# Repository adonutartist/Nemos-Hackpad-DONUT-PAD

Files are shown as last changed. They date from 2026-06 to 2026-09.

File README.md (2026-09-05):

<div align="center">

# Donut Pad :O

*A 12-key macropad with a rotary encoder and OLED display, built for Hack Club's Stardance YSWS.*

Copy of White Creative Project Cover Page

</div>

---

DEMO VIDEO: https://youtube.com/shorts/37Y9ueW4ZXs?feature=share

---

## About

Donut Pad is a 12 key macropad with a rotary encoder and an OLED display, built to function as a gamepad/game controller. It runs using a custom KiCad-designed PCB, and sits inside a integrated plate mounted case topped with a Kintsugi inspired plate with gold/silver cut accents.

## Features

- 12 Mechanical Keys:
  - 4 keys for D-Pad (Up, Down, Left, Right)
  - 4 keys for Action buttons (J, K, U, I)
  - Start and Esc buttons
  - Left and Right shoulder buttons
- EC11 Rotary Encoder for volume (rotation only press is not wired/functional)
- 128x32 OLED display (not functional)
- Seeed XIAO RP2040
- Clean custom PCB
- Sandwich mounting style case

---

## Exploded View

Everything fits together using 4 M3 screws and heatset inserts, integrated plate mount style, with 2 separate printed pieces:

- **Case Shell** where the PCB sits. Designed to be transparent so the PCB remains visible; clear resin printing (or transparent FDA) recommended for the best result. (I did it all black cuz resin is costly)
- **Case Top Plate** holds all keyholes, the OLED cutout, and the rotary encoder cutout. Features a black body with gold cut accents inspired by Kintsugi, the Japanese art of repairing broken pottery with gold.

Assembled view of Donut Pad:

cad model assembled view

Exploded view of Donut Pad:

cad model exploded view

Made in Fusion 360.

---

## BOM (Bill of Materials)

| Component | Qty | Purpose |
|---|-----|---|
| Seeed XIAO RP2040 | 1 | Main controller |
| MX-Style switches | 12 | Key matrix |
| DSA keycaps | 12 | Keycaps |
| EC11 Rotary encoder | 1 | Scroll/volume input |
| 0.91" 128x32 OLED display | 1 | Status display |
| 1N4148 Diodes (THT) | 12 | Matrix ghosting protection |
| M3x16mm screws | 4 | Case assembly |
| M3x5x4mm heatset inserts | 4 | Case assembly |
| Custom PCB | 1 | — |
| 3D printed transparent case shell | 1 | Clear resin / transparent FDA |
| 3D printed Kintsugi-inspired case plate | 1 | Top plate with gold accents |

---

## Circuit Diagram

Designed in KiCad. The silkscreen art includes a custom dooOOnut mascot and the Hack Club logo.

PCB Schematic:

schematic kicad

PCB Board:

PCB kicad

---

## Known Issues

- **OLED display is not functional.** The PCB footprint was laid out assuming the module's pin header runs top-to-bottom (GND, 3V3, SCL, SDA), but the physical module's actual pin order runs bottom-to-top — so the connections ended up reversed on the board. Attempted a rework with a desoldering pump and solder wick to lift the header and rewire it with jumpers, but the pads wouldn't fully clear, so the fix was abandoned for now. Keys and the rotary encoder work fully; the OLED does not currently display anything.
- RGB underglow LEDs were dropped from the design due to DRC errors during PCB routing.

---

## Firmware

Built in the Arduino IDE using:

- Keyboard (built into the Raspberry Pi Pico/RP2040 board core)
- Adafruit GFX
- Adafruit SSD1306

Flash **`Macropad.ino`** to the board. The firmware:

- Scans the 4x3 matrix with debouncing and sends the mapped key on each press.
- Decodes the rotary encoder via interrupt-driven quadrature detection, sending Up/Down arrow keys.
- Drives the OLED status display — currently has no visible effect due to the wiring issue above, but the code is left in place for whenever the display gets rewired.

---

## OLED animation:

- Animated GIF on the OLED.

WIP preview of the OLED animation:



I might add more stuff in the future! That's it for now.

---

## Gallery

<table>
<tr>
<td width="50%">

</td>
<td width="50%">

</td>
</tr>

<tr>
<td width="50%">

</td>
<td width="50%">

</td>
</tr>

<tr>
<td width="50%">
Snapchat-1131476981
</td>
<td width="50%">
Snapchat-2125285501
</td>
</tr>
</table>

---

<div align="center">
nemo
</div>

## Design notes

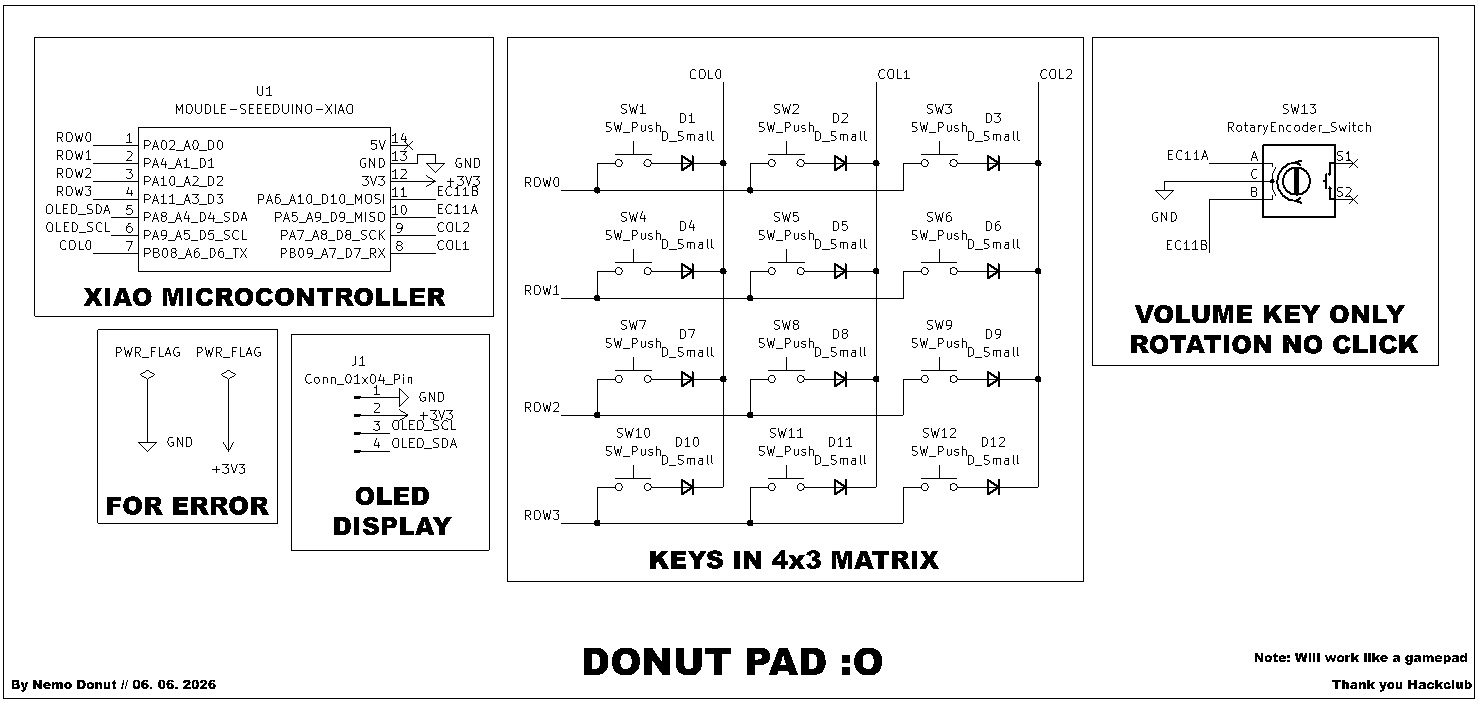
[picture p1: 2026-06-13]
assets/schematic kicad.jpg

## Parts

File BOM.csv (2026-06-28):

1x Seeed XIAO RP2040
12x MX-Style switches
12x DSA keycaps
1x EC11 Rotary encoder
1x 0.91 inch 128x32 OLED display
12x through-hole 1N4148 Diodes
4x M3x16mm screws
4x M3x5mx4mm heatset inserts
PCB (100mmx100mm)
1x 3D printed Transparent case shell (Clear Transparent Resin/Transparent FDA)
1x 3D printed Kintsugi inspired case plate

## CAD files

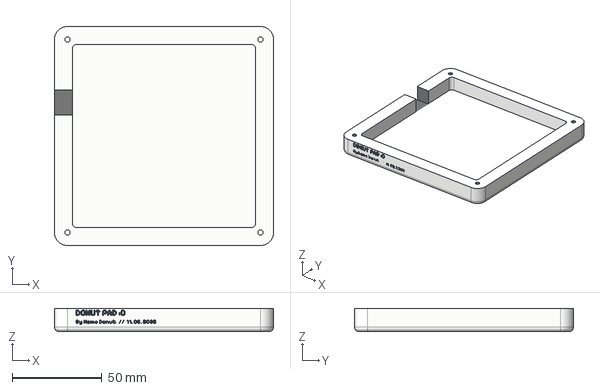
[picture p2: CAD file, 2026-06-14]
Production/Main Body Shell.step
122.0 x 122.0 x 13.0 mm

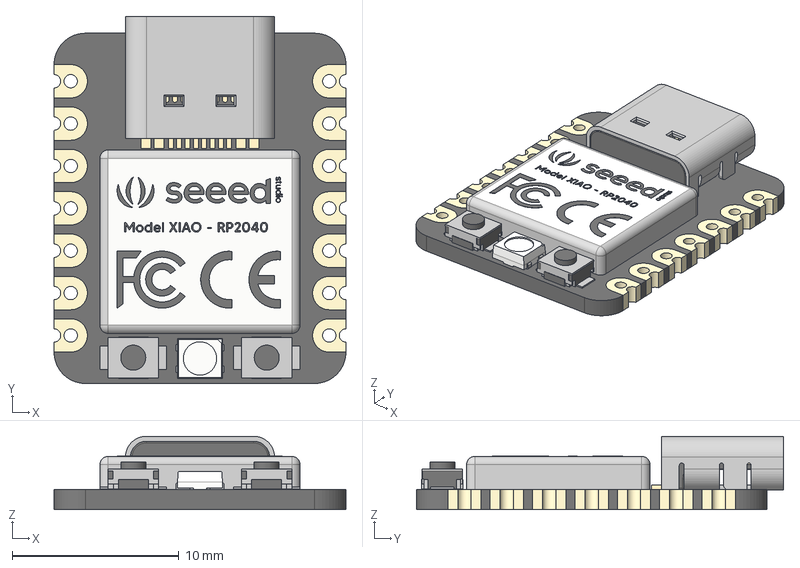
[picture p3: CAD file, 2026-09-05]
assets/Seeed Studio XIAO RP2040 v26.step
17.5 x 22.0 x 4.40 mm
type-c v2
smd_button v3
DOUT
DIN
VSS
VDD
smd_button v3(Mirror)

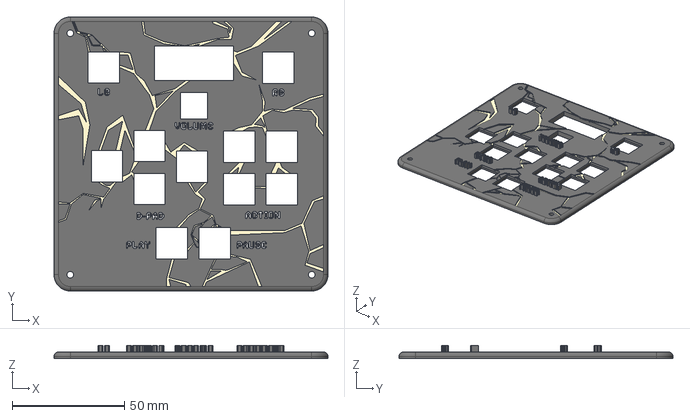
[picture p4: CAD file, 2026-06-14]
Production/Top Plate.step
122.0 x 122.0 x 6.00 mm

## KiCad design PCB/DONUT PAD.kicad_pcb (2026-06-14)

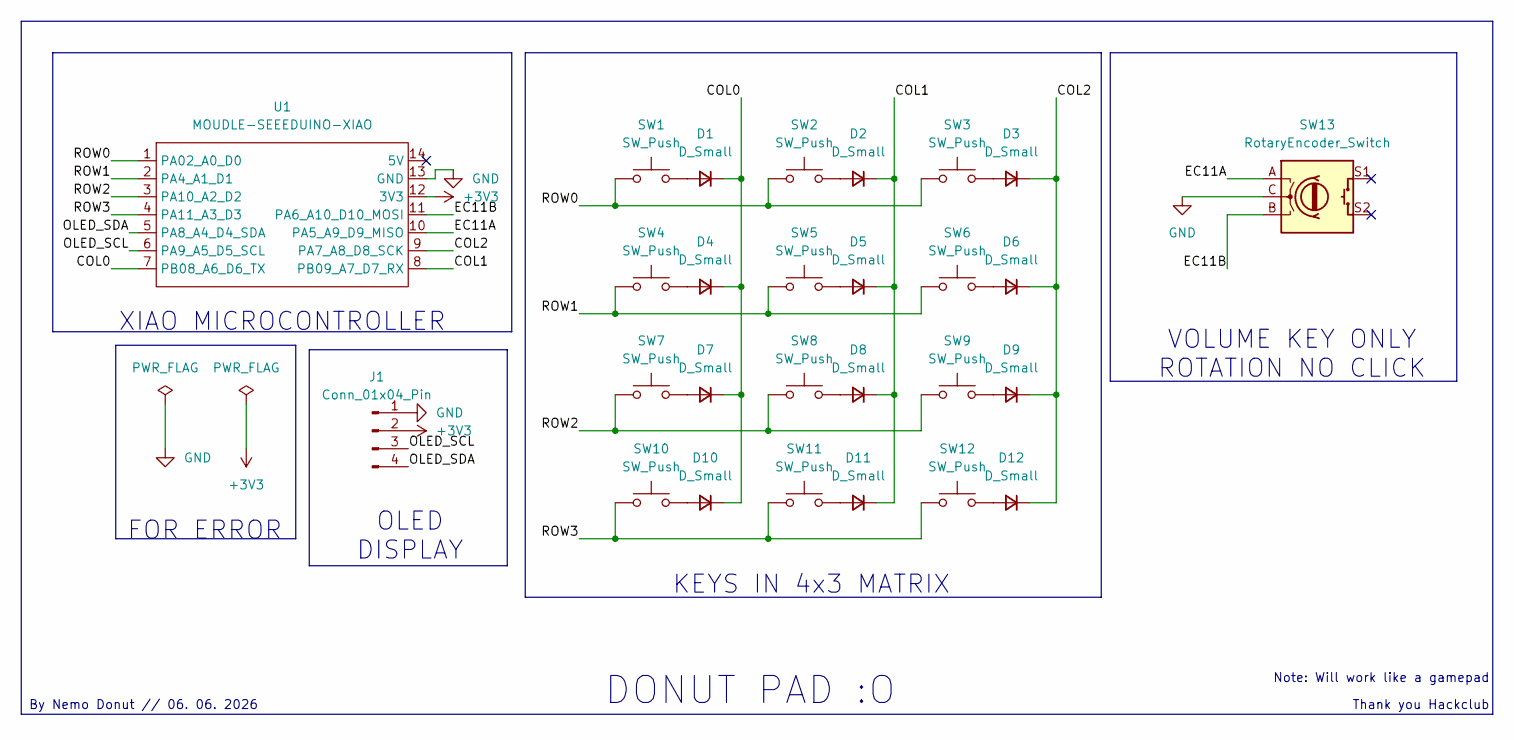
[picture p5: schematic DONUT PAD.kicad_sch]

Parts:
D1, D2, D3, D4, D5, D6, D7, D8, D9, D10, D11, D12: D_Small; D_DO-35_SOD27_P7.62mm_Horizontal
J1: Conn_01x04_Pin; PinHeader_1x04_P2.54mm_Vertical
SW1, SW2, SW3, SW4, SW5, SW6, SW7, SW8, SW9, SW10, SW11, SW12: SW_Push; SW_Cherry_MX_1.00u_PCB
SW13: RotaryEncoder_Switch; RotaryEncoder_Alps_EC11E-Switch_Vertical_H20mm
U1: MOUDLE-SEEEDUINO-XIAO; XIAO-Generic-Hybrid-14P-2.54-21X17.8MM

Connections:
+3V3: J1.2, U1.12 (3V3)
/COL0: D1.1 (K), D4.1 (K), D7.1 (K), D10.1 (K), U1.7 (PB08_A6_D6_TX)
/COL1: D2.1 (K), D5.1 (K), D8.1 (K), D11.1 (K), U1.8 (PB09_A7_D7_RX)
/COL2: D3.1 (K), D6.1 (K), D9.1 (K), D12.1 (K), U1.9 (PA7_A8_D8_SCK)
/EC11A: SW13.A, U1.10 (PA5_A9_D9_MISO)
/EC11B: SW13.B, U1.11 (PA6_A10_D10_MOSI)
/OLED_SCL: J1.3, U1.6 (PA9_A5_D5_SCL)
/OLED_SDA: J1.4, U1.5 (PA8_A4_D4_SDA)
/ROW0: SW1.1, SW2.1, SW3.1, U1.1 (PA02_A0_D0)
/ROW1: SW4.1, SW5.1, SW6.1, U1.2 (PA4_A1_D1)
/ROW2: SW7.1, SW8.1, SW9.1, U1.3 (PA10_A2_D2)
/ROW3: SW10.1, SW11.1, SW12.1, U1.4 (PA11_A3_D3)
GND: J1.1, SW13.C, U1.13 (GND)
unnamed: D1.2 (A), SW1.2
unnamed: D2.2 (A), SW2.2
unnamed: D3.2 (A), SW3.2
unnamed: D4.2 (A), SW4.2
unnamed: D5.2 (A), SW5.2
unnamed: D6.2 (A), SW6.2
unnamed: D7.2 (A), SW7.2
unnamed: D8.2 (A), SW8.2
unnamed: D9.2 (A), SW9.2
unnamed: D10.2 (A), SW10.2
unnamed: D11.2 (A), SW11.2
unnamed: D12.2 (A), SW12.2

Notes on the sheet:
Note: Will work like a gamepad
Thank you Hackclub
OLED DISPLAY
KEYS IN 4x3 MATRIX
VOLUME KEY ONLY ROTATION NO CLICK
DONUT PAD :O
By Nemo Donut // 06. 06. 2026
FOR ERROR
XIAO MICROCONTROLLER

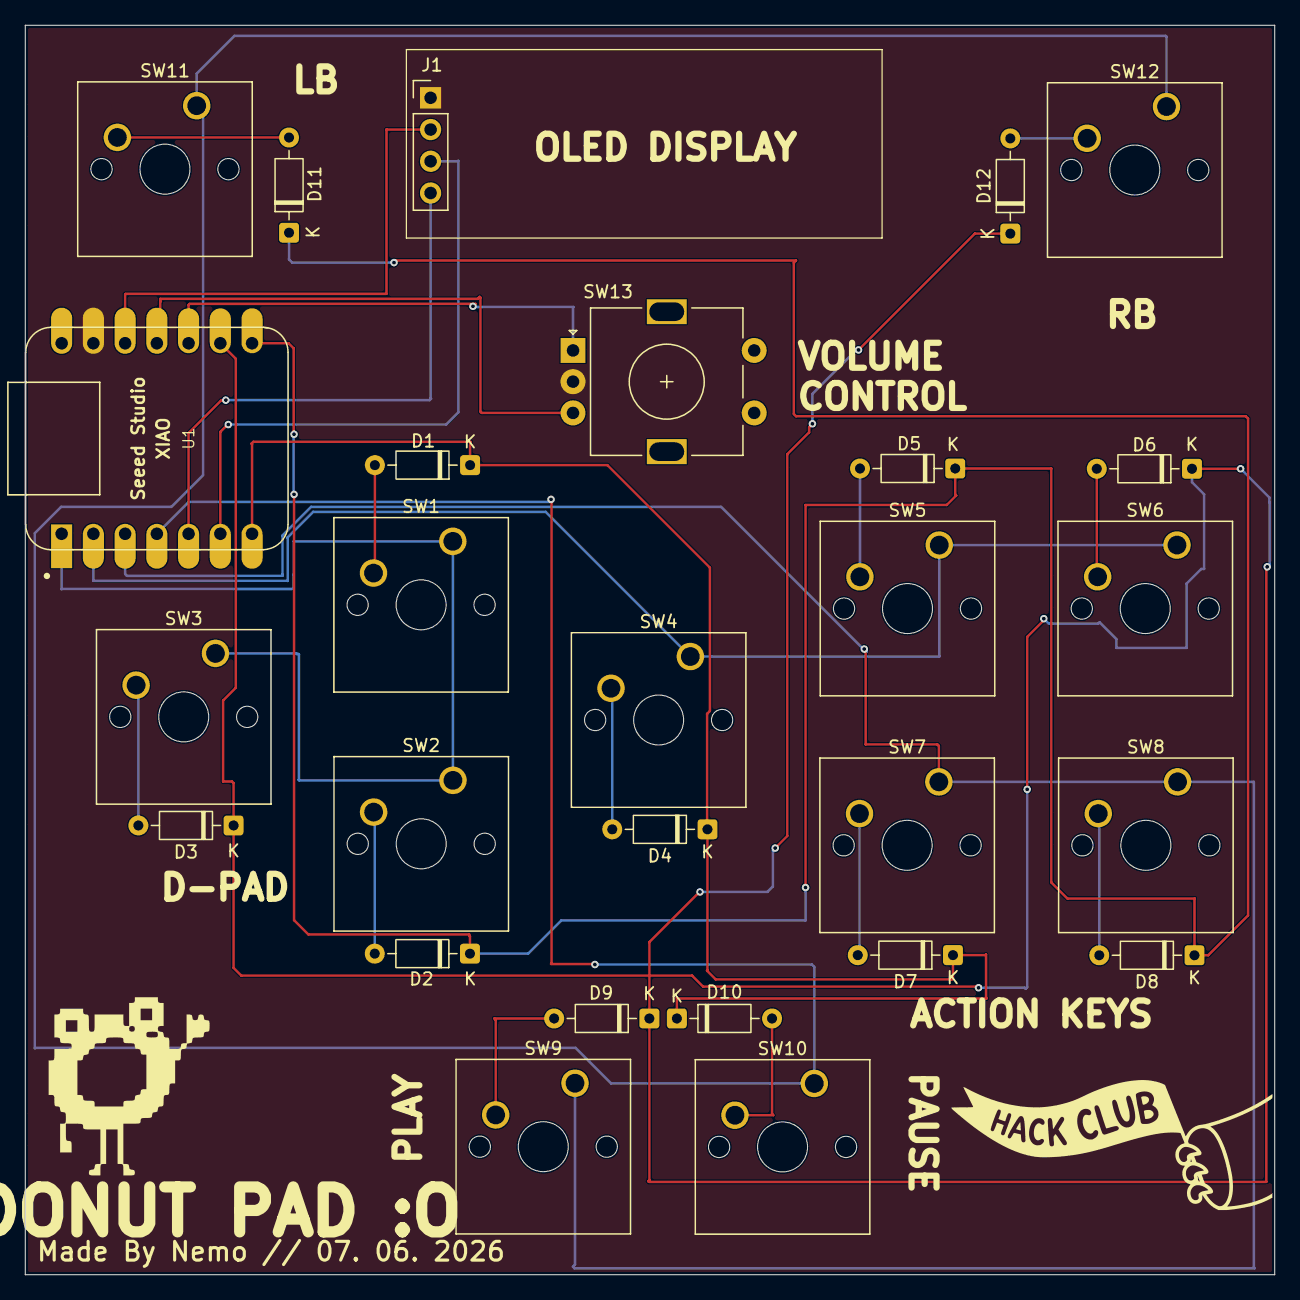
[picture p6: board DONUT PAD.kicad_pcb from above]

Board: 2 copper layers, 100.0 x 100.0 mm, 27 parts (0 on the bottom side), 25 nets.

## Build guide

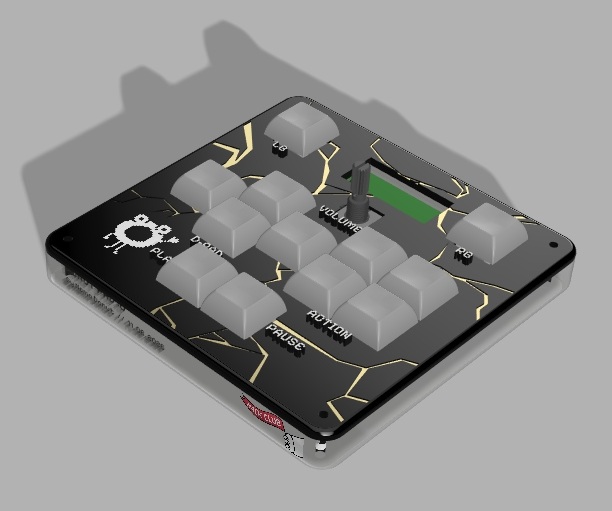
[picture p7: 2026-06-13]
assets/cad model assembled view.jpg

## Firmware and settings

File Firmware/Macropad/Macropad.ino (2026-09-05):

 #include <Adafruit_TinyUSB.h>
Adafruit_USBD_HID usb_hid;
enum {
  RID_KEYBOARD = 1,
  RID_CONSUMER = 2
};
uint8_t const hid_report_descriptor[] = {

  0x05, 0x01,                    // Usage Page (Generic Desktop)
  0x09, 0x06,                    // Usage (Keyboard)
  0xA1, 0x01,                    // Collection (Application)

  0x85, RID_KEYBOARD,            // Report ID 1

  0x05, 0x07,                    // Usage Page (Keyboard/Keypad)

  // Modifier keys
  0x19, 0xE0,
  0x29, 0xE7,
  0x15, 0x00,
  0x25, 0x01,
  0x75, 0x01,
  0x95, 0x08,
  0x81, 0x02,

  // Reserved byte
  0x75, 0x08,
  0x95, 0x01,
  0x81, 0x01,

  // 8 simultaneous keys
  0x15, 0x00,
  0x25, 0x65,
  0x19, 0x00,
  0x29, 0x65,
  0x75, 0x08,
  0x95, 0x08,
  0x81, 0x00,

  0xC0,                          // End keyboard

  0x05, 0x0C,                    // Usage Page (Consumer)
  0x09, 0x01,                    // Usage (Consumer Control)
  0xA1, 0x01,                    // Collection

  0x85, RID_CONSUMER,            // Report ID 2

  0x15, 0x00,                    // Logical Minimum
  0x26, 0xFF, 0x03,              // Logical Maximum 0x03FF

  0x19, 0x00,                    // Usage Minimum
  0x2A, 0xFF, 0x03,              // Usage Maximum 0x03FF

  0x75, 0x10,                    // Report Size = 16 bits
  0x95, 0x01,                    // Report Count = 1

  0x81, 0x00,                    // Input

  0xC0                           // End consumer
};
const uint8_t rowPins[4] = {
  D0, D1, D2, D3
};
const uint8_t colPins[3] = {
  D6, D7, D8
};

// KEY MAPPING
//
// SW1 = W + UP
// SW2 = S + DOWN
// SW3 = A + LEFT
// SW4 = D + RIGHT
//
// SW5 = J
// SW6 = K
// SW7 = U
// SW8 = I
//
// SW9  = SPACE
// SW10 = ESC
// SW11 = Q
// SW12 = E

// Encoder = Volume

bool keyState[12] = { false };
const uint8_t encoderA = D9;
const uint8_t encoderB = D10;
uint8_t encoderState = 0;
int8_t encoderAccumulator = 0;
const int8_t encoderTable[16] = {
   0, -1,  1,  0,
   1,  0,  0, -1,
  -1,  0,  0,  1,
   0,  1, -1,  0
};
void volumeUp() {
  if (!usb_hid.ready()) {
    return;
  }
  usb_hid.sendReport16(
    RID_CONSUMER,
    HID_USAGE_CONSUMER_VOLUME_INCREMENT
  );
  delay(3);
  usb_hid.sendReport16(
    RID_CONSUMER,
    0
  );
}
void volumeDown() {
  if (!usb_hid.ready()) {
    return;
  }
  usb_hid.sendReport16(
    RID_CONSUMER,
    HID_USAGE_CONSUMER_VOLUME_DECREMENT
  );
  delay(3);
  usb_hid.sendReport16(
    RID_CONSUMER,
    0
  );
}
void updateEncoder() {
  uint8_t A = digitalRead(encoderA);
  uint8_t B = digitalRead(encoderB);
  uint8_t newState = (A << 1) | B;
  if (newState == encoderState) {
    return;
  }
  uint8_t index = (encoderState << 2) | newState;
  encoderAccumulator += encoderTable[index];
  encoderState = newState;
  if (encoderAccumulator >= 4) {
    volumeDown();
    encoderAccumulator = 0;
  }
  else if (encoderAccumulator <= -4) {
    volumeUp();
    encoderAccumulator = 0;
  }
}
void addKey(
  uint8_t report[],
  int &count,
  uint8_t key
) {
  if (count < 8) {
    report[2 + count] = key;
    count++;
  }
}
void sendKeyboardReport() {
  uint8_t report[10] = { 0 };
  int count = 0;
  for (int i = 0; i < 12; i++) {
    if (!keyState[i]) {
      continue;
    }
    if (i == 0) {
      addKey(report, count, HID_KEY_W);
      addKey(report, count, HID_KEY_ARROW_UP);
    }
    else if (i == 1) {
      addKey(report, count, HID_KEY_S);
      addKey(report, count, HID_KEY_ARROW_DOWN);
    }
    else if (i == 2) {
      addKey(report, count, HID_KEY_A);
      addKey(report, count, HID_KEY_ARROW_LEFT);
    }
    else if (i == 3) {
      addKey(report, count, HID_KEY_D);
      addKey(report, count, HID_KEY_ARROW_RIGHT);
    }
    else if (i == 4) {
      addKey(report, count, HID_KEY_J);
    }
    else if (i == 5) {
      addKey(report, count, HID_KEY_K);
    }
    else if (i == 6) {
      addKey(report, count, HID_KEY_U);
    }
    else if (i == 7) {
      addKey(report, count, HID_KEY_I);
    }
    else if (i == 8) {
      addKey(report, count, HID_KEY_SPACE);
    }
    else if (i == 9) {
      addKey(report, count, HID_KEY_ESCAPE);
    }
    else if (i == 10) {
      addKey(report, count, HID_KEY_Q);
    }
    else if (i == 11) {
      addKey(report, count, HID_KEY_E);
    }
  }
  usb_hid.sendReport(
    RID_KEYBOARD,
    report,
    sizeof(report)
  );
}
void setup() {
  for (int r = 0; r < 4; r++) {
    pinMode(rowPins[r], OUTPUT);
    digitalWrite(rowPins[r], LOW);
  }
  for (int c = 0; c < 3; c++) {

    pinMode(
      colPins[c],
      INPUT_PULLDOWN
    );
  }
  pinMode(
    encoderA,
    INPUT_PULLUP
  );
  pinMode(
    encoderB,
    INPUT_PULLUP
  );
  encoderState =
    (digitalRead(encoderA) << 1) |
     digitalRead(encoderB);
  usb_hid.setPollInterval(2);
  usb_hid.setReportDescriptor(
    hid_report_descriptor,
    sizeof(hid_report_descriptor)
  );
  usb_hid.begin();
  while (!TinyUSBDevice.mounted()) {
    delay(10);
  }
}
void loop() {
  if (!usb_hid.ready()) {
    return;
  }
  updateEncoder();
  for (int r = 0; r < 4; r++) {
    digitalWrite(
      rowPins[r],
      HIGH
    );
    delayMicroseconds(50);
    for (int c = 0; c < 3; c++) {
      int key = r * 3 + c;
      bool pressed =
        digitalRead(colPins[c]);

      keyState[key] = pressed;
    }
    digitalWrite(
      rowPins[r],
      LOW
    );
  }
  sendKeyboardReport();
  delay(2);
}

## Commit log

2026-06-14 PCB uploaded
    [DONUT PAD.kicad_pcb, DONUT PAD.kicad_sch]
2026-06-14 production upload
    [Main Body Shell.step, Top Plate.step]
2026-06-28 Add Bill of Materials for project components
    [BOM.csv]
